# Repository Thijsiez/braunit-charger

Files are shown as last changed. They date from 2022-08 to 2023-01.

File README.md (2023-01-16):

# braunit-charger

## :construction: WIP :construction:
This repo is currently a work-in-progress. I will add more information and documentation when the design of the charger is done.  
As long as this message is here, I'm open to suggestions but please do not assume anything is done or will work without issues.

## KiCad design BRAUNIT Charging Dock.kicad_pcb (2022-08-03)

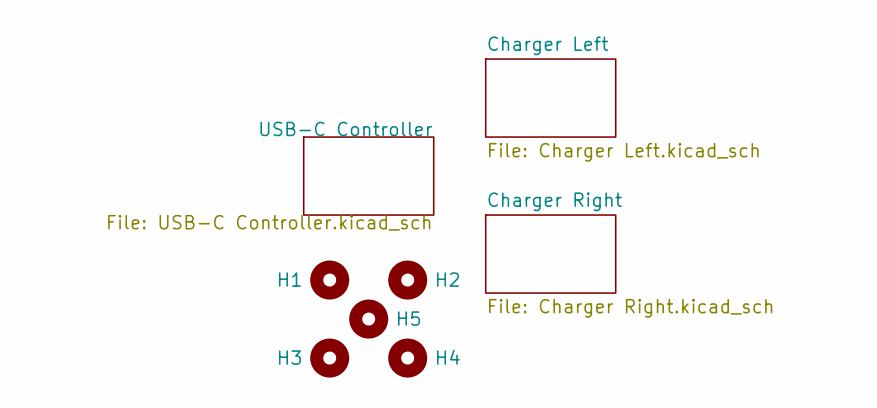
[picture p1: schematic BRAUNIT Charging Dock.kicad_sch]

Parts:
H1, H2, H3, H4, H5: MountingHole; MountingHole_2.7mm_M2.5_DIN912_Keepout

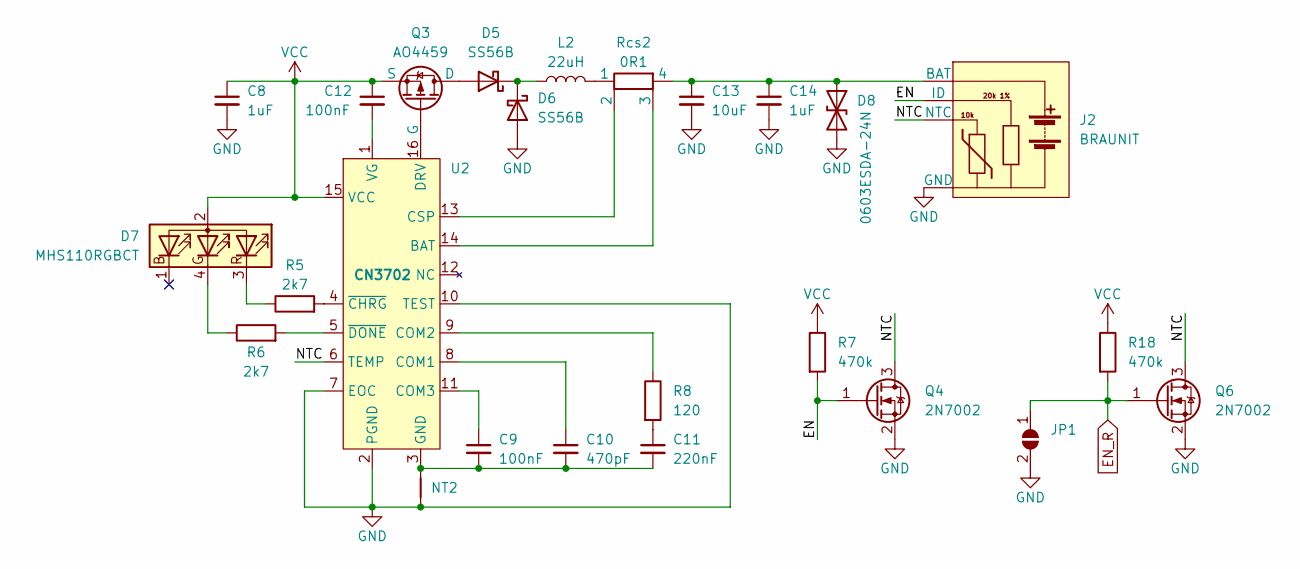
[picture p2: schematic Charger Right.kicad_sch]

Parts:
C8, C14: 1uF; C_0805_2012Metric; LCSC C91185
C9, C12: 100nF; C_0603_1608Metric; LCSC C14663
C10: 470pF; C_0603_1608Metric; LCSC C107092
C11: 220nF; C_0603_1608Metric; LCSC C107083
C13: 10uF; C_1206_3216Metric; LCSC C109464
D5, D6: SS56B; D_SMB; LCSC C382814
D7: MHS110RGBCT; LED_RGB_Meihua_MHS110RGBCT; LCSC C389528
D8: 0603ESDA-24N; D_0603_1608Metric; LCSC C316056
J2: BRAUNIT; Blade_1x04_P2.5mm_Vertical_BRAUNIT_Loose
JP1: SolderJumper_2_Open; SolderJumper-2_P1.3mm_Open_TrianglePad1.0x1.5mm
L2: 22uH; L_Sunltech_SLO0630H; LCSC C207843
NT2: NetTie_2; NetTie-2_SMD_Pad0.5mm
Q3: AO4459; SOIC-8_3.9x4.9mm_P1.27mm; LCSC C49047
Q4, Q6: 2N7002; SOT-23; LCSC C8545
R5, R6: 2k7; R_0603_1608Metric; LCSC C114612
R7, R18: 470k; R_0603_1608Metric; LCSC C114622
R8: 120; R_0603_1608Metric; LCSC C114640
Rcs2: 0R1; R_Shunt_2010_5025Metric; LCSC C309644
U2: CN3702; TSSOP-16_4.4x5mm_P0.65mm; LCSC C40655

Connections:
/Charger Right/EN: J2.2 (ID), Q4.1 (G), R7.2
/Charger Right/NTC: J2.3 (NTC), Q4.3 (D), Q6.3 (D), U2.6 (TEMP)
EN_R: JP1.1 (A), Q6.1 (G), R18.2; also elsewhere on the board
GND: C8.2, C13.2, C14.2, D6.2 (A), D8.2 (A2), J2.4 (GND), JP1.2 (B), NT2.2, Q4.2 (S), Q6.2 (S), U2.2 (PGND), U2.7 (EOC), U2.10 (TEST); also elsewhere on the board
unnamed: C9.1, U2.11 (COM3)
unnamed: C10.1, U2.8 (COM1)
unnamed: C9.2, C10.2, C11.2, NT2.1, U2.3 (GND)
unnamed: C11.1, R8.2
unnamed: C12.2, U2.1 (VG)
unnamed: C13.1, C14.1, D8.1 (A1), J2.1 (BAT), Rcs2.4
unnamed: D5.1 (K), D6.1 (K), L2.1
unnamed: D5.2 (A), Q3.5 (D), Q3.6 (D), Q3.7 (D), Q3.8 (D)
unnamed: D7.3 (RK), R5.1
unnamed: D7.4 (GK), R6.1
unnamed: L2.2, Rcs2.1
unnamed: Q3.4 (G), U2.16 (DRV)
unnamed: R5.2, U2.4 (~CHRG)
unnamed: R6.2, U2.5 (~DONE)
unnamed: R8.1, U2.9 (COM2)
unnamed: Rcs2.2, U2.13 (CSP)
unnamed: Rcs2.3, U2.14 (BAT)
VCC: C8.1, C12.1, D7.2 (A), Q3.1 (S), Q3.2 (S), Q3.3 (S), R7.1, R18.1, U2.15 (VCC); also elsewhere on the board

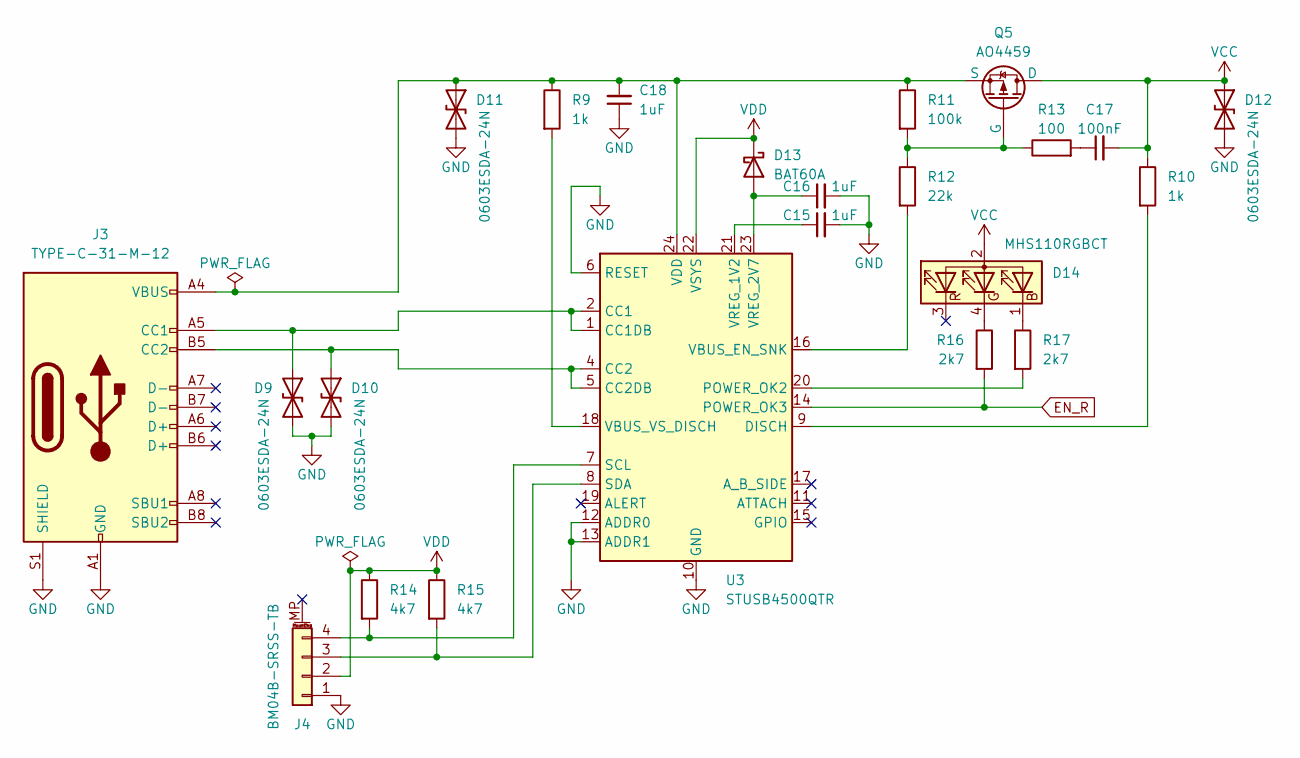
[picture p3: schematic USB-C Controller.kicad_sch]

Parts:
C15, C16, C18: 1uF; C_0805_2012Metric; LCSC C91185
C17: 100nF; C_0603_1608Metric; LCSC C14663
D9, D10, D11, D12: 0603ESDA-24N; D_0603_1608Metric; LCSC C316056
D13: BAT60A; D_SOD-323; LCSC C117485
D14: MHS110RGBCT; LED_RGB_Meihua_MHS110RGBCT; LCSC C389528
J3: TYPE-C-31-M-12; USB_C_Receptacle_HRO_TYPE-C-31-M-12; LCSC C165948
J4: BM04B-SRSS-TB; JST_SH_BM04B-SRSS-TB_1x04-1MP_P1.00mm_Vertical; LCSC C160390
Q5: AO4459; SOIC-8_3.9x4.9mm_P1.27mm; LCSC C49047
R9, R10: 1k; R_0603_1608Metric; LCSC C22548
R11: 100k; R_0603_1608Metric; LCSC C14675
R12: 22k; R_0603_1608Metric; LCSC C114065
R13: 100; R_0603_1608Metric; LCSC C105588
R14, R15: 4k7; R_0603_1608Metric; LCSC C99782
R16, R17: 2k7; R_0603_1608Metric; LCSC C114612
U3: STUSB4500QTR; QFN-24-1EP_4x4mm_P0.5mm_EP2.7x2.7mm; LCSC C2678061

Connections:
EN_R: R16.2, U3.14 (POWER_OK3); also elsewhere on the board
GND: C15.2, C16.2, C18.1, D9.2 (A2), D10.2 (A2), D11.2 (A2), D12.2 (A2), J3.A1 (GND), J3.A12 (GND), J3.B1 (GND), J3.B12 (GND), J3.S1 (SHIELD), J4.1, U3.6 (RESET), U3.10 (GND), U3.12 (ADDR0), U3.13 (ADDR1), U3.25 (GND); also elsewhere on the board
unnamed: C15.1, U3.21 (VREG_1V2)
unnamed: C16.1, D13.2 (A), U3.23 (VREG_2V7)
unnamed: C17.1, R13.2
unnamed: C18.2, D11.1 (A1), J3.A4 (VBUS), J3.A9 (VBUS), J3.B4 (VBUS), J3.B9 (VBUS), Q5.1 (S), Q5.2 (S), Q5.3 (S), R9.1, R11.1, U3.24 (VDD)
unnamed 30: D9.1 (A1), J3.A5 (CC1), U3.1 (CC1DB), U3.2 (CC1); also elsewhere on the board
unnamed: D10.1 (A1), J3.B5 (CC2), U3.4 (CC2), U3.5 (CC2DB)
unnamed: D14.1 (BK), R17.1
unnamed: D14.4 (GK), R16.1
unnamed: J4.3, R15.2, U3.8 (SDA)
unnamed: J4.4, R14.2, U3.7 (SCL)
unnamed 40: Q5.4 (G), R11.2, R12.1, R13.1; also elsewhere on the board
unnamed: R9.2, U3.18 (VBUS_VS_DISCH)
unnamed: R10.2, U3.9 (DISCH)
unnamed 49: R12.2, U3.16 (VBUS_EN_SNK); also elsewhere on the board
unnamed: R17.2, U3.20 (POWER_OK2)
VCC: C17.2, D12.1 (A1), D14.2 (A), Q5.5 (D), Q5.6 (D), Q5.7 (D), Q5.8 (D), R10.1; also elsewhere on the board
VDD: D13.1 (K), J4.2, R14.1, R15.1, U3.22 (VSYS)

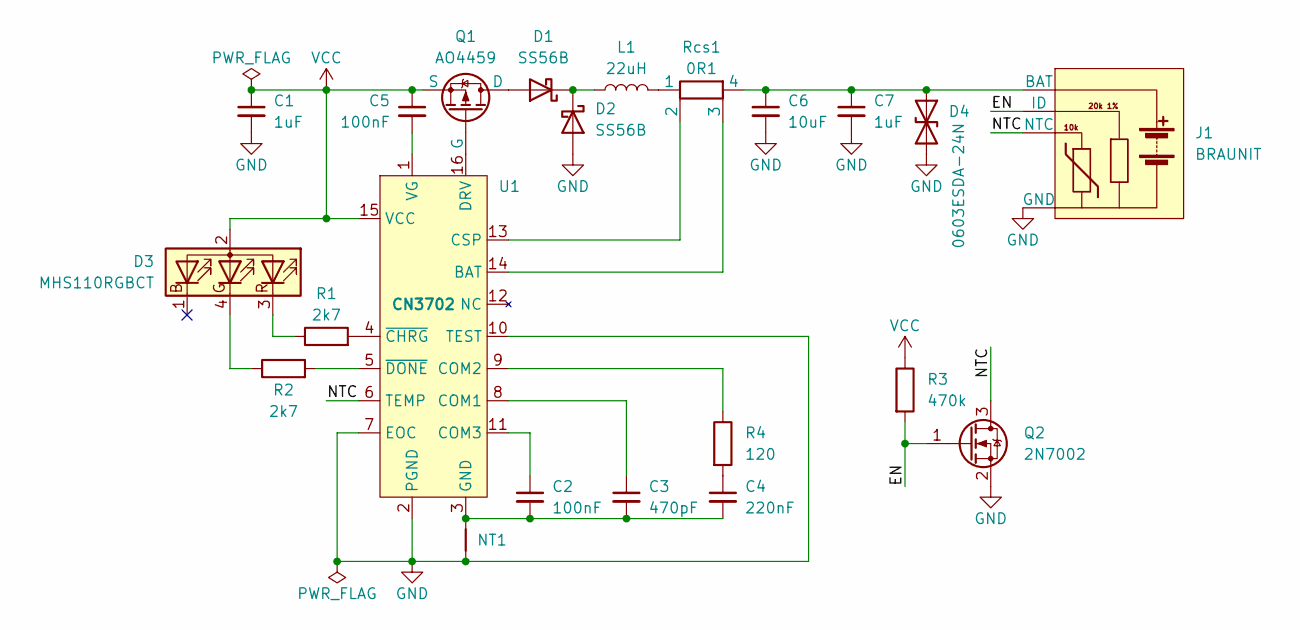
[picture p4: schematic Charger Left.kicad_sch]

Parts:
C1, C7: 1uF; C_0805_2012Metric; LCSC C91185
C2, C5: 100nF; C_0603_1608Metric; LCSC C14663
C3: 470pF; C_0603_1608Metric; LCSC C107092
C4: 220nF; C_0603_1608Metric; LCSC C107083
C6: 10uF; C_1206_3216Metric; LCSC C109464
D1, D2: SS56B; D_SMB; LCSC C382814
D3: MHS110RGBCT; LED_RGB_Meihua_MHS110RGBCT; LCSC C389528
D4: 0603ESDA-24N; D_0603_1608Metric; LCSC C316056
J1: BRAUNIT; Blade_1x04_P2.5mm_Vertical_BRAUNIT_Loose
L1: 22uH; L_Sunltech_SLO0630H; LCSC C207843
NT1: NetTie_2; NetTie-2_SMD_Pad0.5mm
Q1: AO4459; SOIC-8_3.9x4.9mm_P1.27mm; LCSC C49047
Q2: 2N7002; SOT-23; LCSC C8545
R1, R2: 2k7; R_0603_1608Metric; LCSC C114612
R3: 470k; R_0603_1608Metric; LCSC C114622
R4: 120; R_0603_1608Metric; LCSC C114640
Rcs1: 0R1; R_Shunt_2010_5025Metric; LCSC C309644
U1: CN3702; TSSOP-16_4.4x5mm_P0.65mm; LCSC C40655

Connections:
/Charger Left/EN: J1.2 (ID), Q2.1 (G), R3.2
/Charger Left/NTC: J1.3 (NTC), Q2.3 (D), U1.6 (TEMP)
GND: C1.2, C6.2, C7.2, D2.2 (A), D4.2 (A2), J1.4 (GND), NT1.2, Q2.2 (S), U1.2 (PGND), U1.7 (EOC), U1.10 (TEST); also elsewhere on the board
unnamed: C2.1, U1.11 (COM3)
unnamed: C2.2, C3.2, C4.2, NT1.1, U1.3 (GND)
unnamed: C3.1, U1.8 (COM1)
unnamed: C4.1, R4.2
unnamed: C5.2, U1.1 (VG)
unnamed: C6.1, C7.1, D4.1 (A1), J1.1 (BAT), Rcs1.4
unnamed: D1.1 (K), D2.1 (K), L1.1
unnamed: D1.2 (A), Q1.5 (D), Q1.6 (D), Q1.7 (D), Q1.8 (D)
unnamed: D3.3 (RK), R1.1
unnamed: D3.4 (GK), R2.1
unnamed: L1.2, Rcs1.1
unnamed: Q1.4 (G), U1.16 (DRV)
unnamed: R1.2, U1.4 (~CHRG)
unnamed: R2.2, U1.5 (~DONE)
unnamed: R4.1, U1.9 (COM2)
unnamed: Rcs1.2, U1.13 (CSP)
unnamed: Rcs1.3, U1.14 (BAT)
VCC: C1.1, C5.1, D3.2 (A), Q1.1 (S), Q1.2 (S), Q1.3 (S), R3.1, U1.15 (VCC); also elsewhere on the board

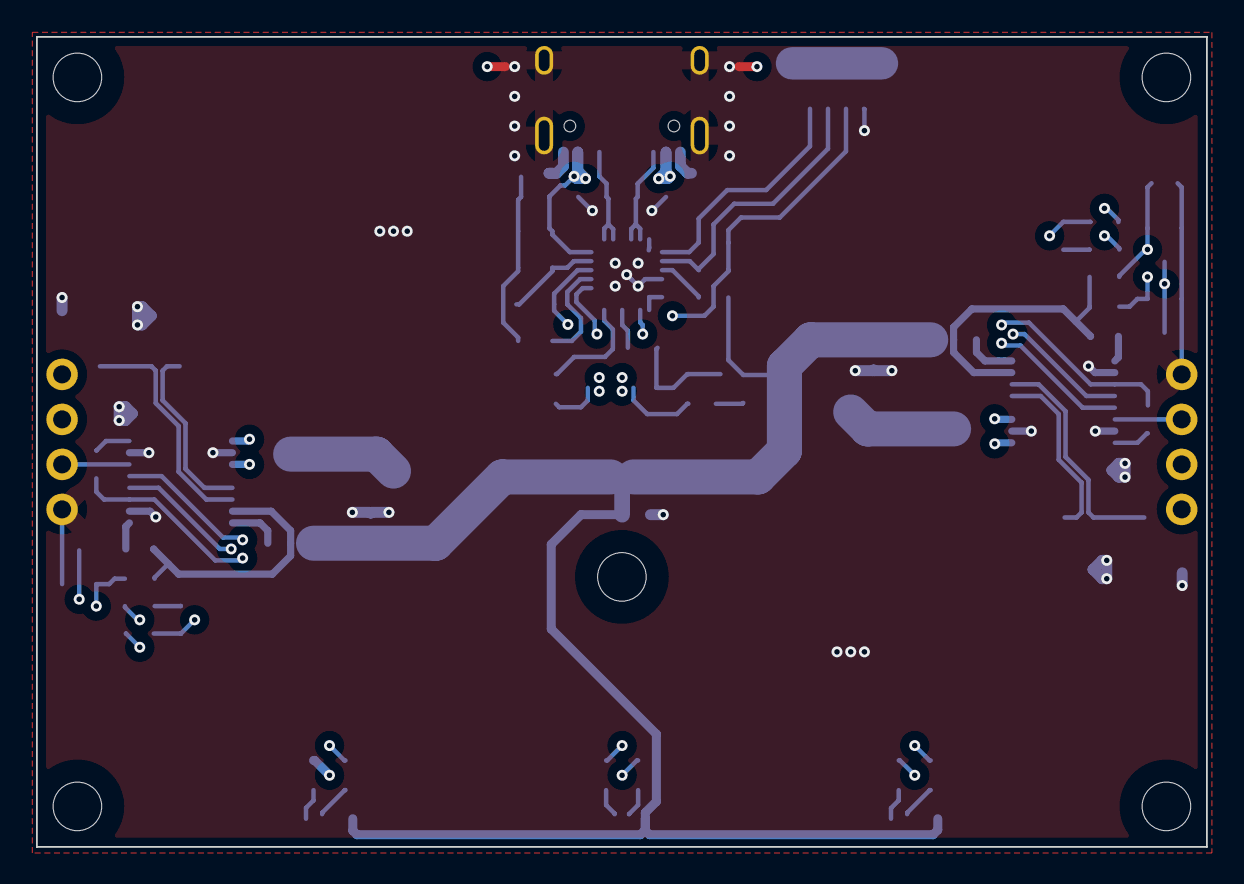
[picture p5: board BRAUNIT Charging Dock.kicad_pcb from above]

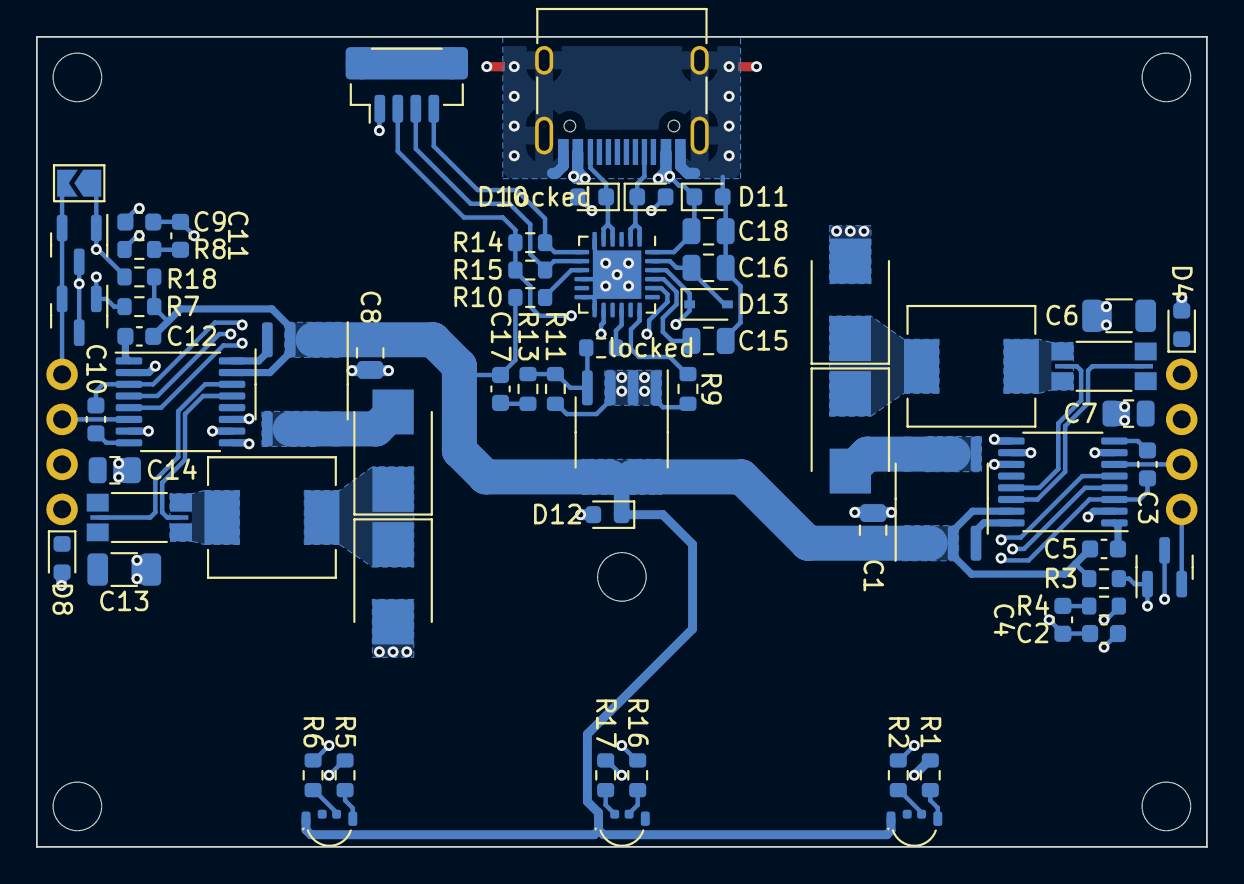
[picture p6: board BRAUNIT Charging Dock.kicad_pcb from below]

Board: 4 copper layers, 65.0 x 45.0 mm, 75 parts (66 on the bottom side), 57 nets.

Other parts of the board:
locked: 0603ESDA-24N; D_0603_1608Metric
locked#2: 22k; R_0603_1608Metric

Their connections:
GND: locked.2 (A2); also elsewhere on the board
unnamed 30: locked.1 (A1); also elsewhere on the board
unnamed 40: locked#2.1; also elsewhere on the board
unnamed 49: locked#2.2; also elsewhere on the board

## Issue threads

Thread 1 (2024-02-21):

Charging pins

shmick, 2024-02-21:
Would you happen to know what pins on the Braunit battery are used for charging with 8.4v?

Thijsiez, 2024-02-21:
Hej Steve,

Actually, I do! For this project I fully reverse-engineered the electronics in the battery packs and a charger (contained in an IKEA Bluetooth speaker), I just haven't documented that anywhere. This project fell by the wayside and I started doing other stuff.

Anyway, if you look at the micro USB port, with the 4-pin blade connector facing up, the left pin (closest to the USB connector) will be your pack positive, directly connected to the cell positive.
The right pin (farthest away from the USB connector) is your negative and connects to the cell negative through two N-channel MOSFETs, controlled by an ABLIC S-8252 cell protection IC.

When using the 4-pin blade connector to charge at 8.4V, or discharged for that matter, the cells will still be protected (not balanced actively), and you're fully bypassing the USB charging circuit.

Hope that helps!

shmick, 2024-02-21:
Thijs,

Thanks for the info!

My plan is to use some small solar panels to keep the Braunit battery topped up in an Ikea Fyrtur shade using a TP5100 connected to the battery.

Thanks again.

Thijsiez, 2024-02-21:
That sounds like a great improvement! I have two of the FYRTUR myself and I'm pretty sure that if you open up the side with the battery, it exposes a black and red lead to the battery connector :)

Closed 2024-02-28.

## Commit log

2022-04-29 Move project from Dropbox to GitHub
    [BRAUNIT Charging Dock.kicad_sch, Charger Left.kicad_sch, Charger Right.kicad_sch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]
2022-04-29 Add some resistors and caps
    [BRAUNIT Charging Dock.kicad_sch, Charger Left.kicad_sch, Charger Right.kicad_sch]
2022-04-29 Add BRAUNIT connector and battery detect/charge enable
    [BRAUNIT Charging Dock.kicad_sch, Charger Left.kicad_sch, Charger Right.kicad_sch]
2022-04-29 Add LCSC part numbers for most components
    [BRAUNIT Charging Dock.kicad_sch, Charger Left.kicad_sch, Charger Right.kicad_sch]
2022-04-29 Add status indicator LED
    [BRAUNIT Charging Dock.kicad_sch, Charger Left.kicad_sch, Charger Right.kicad_sch]
2022-04-29 Specify LED, resistors, and start on USB-C circuit
    [BRAUNIT Charging Dock.kicad_sch, Charger Left.kicad_sch, Charger Right.kicad_sch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]
2022-04-29 Add USB-C circuit components
    [BRAUNIT Charging Dock.kicad_sch, USB-C Controller.kicad_sch]
2022-05-01 Add ESD protection, I2C header, and specify passives
    [BRAUNIT Charging Dock.kicad_sch, Charger Left.kicad_sch, Charger Right.kicad_sch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]
2022-05-02 Add USB-C status indicator LED and right charger enable
    [BRAUNIT Charging Dock.kicad_sch, Charger Right.kicad_sch, USB-C Controller.kicad_sch]
2022-05-02 Replace USB-C connector with USB 2.0 version
    [USB-C Controller.kicad_sch]
2022-05-02 Replace JST SH connector symbol with Mounting Pin version
    [USB-C Controller.kicad_sch]
2022-05-28 Initial board layout
    [BRAUNIT Charging Dock.kicad_pcb, BRAUNIT Charging Dock.kicad_sch, Charger Left.kicad_sch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]
2022-06-03 WIP traces
    [BRAUNIT Charging Dock.kicad_pcb, BRAUNIT Charging Dock.kicad_sch, Charger Right.kicad_sch]
2022-06-15 Change to 4-layer board and do some routing
    [BRAUNIT Charging Dock.kicad_pcb, BRAUNIT Charging Dock.kicad_sch, Charger Right.kicad_sch]
2022-08-03 Only output connections to go :)
    [BRAUNIT Charging Dock.kicad_pcb, BRAUNIT Charging Dock.kicad_sch]
